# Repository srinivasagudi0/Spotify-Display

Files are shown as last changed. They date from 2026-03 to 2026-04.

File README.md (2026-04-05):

# 🎵 Spotify Display (ESP32 + TFT)

A small project I made that shows my current Spotify track on a TFT screen using an ESP32.

---

## 🚀 Features

- Shows song name + artist  
- Connects to Spotify over WiFi  
- 3 buttons: play/pause, next, previous  
- Runs on ESP32 C3 Mini  

---

## 🧠 What I Did

- Set up Spotify API on the ESP32  
- Built a simple UI for the display  
- Wired buttons for playback control  
- Made a compact enclosure  

---

## 🧰 Parts

- ESP32 C3 Mini  
- 1.8" TFT (ST7735)  
- 3 buttons  
- Wires / soldering  

---

## 🔌 Wiring

| Part | Pin |
|---|-----|
| TFT CS | 5 |
| TFT DC | 2 |
| TFT RST  | 4 |
| TFT MOSI | 6 |
| TFT SCLK | 7 |
| Prev Btn | 8 |
| Play Btn | 9 |
| Next Btn | 10 |

---

## ▶️ How It Works

ESP32 connects to WiFi → gets current track from Spotify → displays it → buttons control playback.

---

## 🛠 Future Ideas

- Album art  
- Battery  
- Better UI  
- Volume control  

---

## 👤 Me

Srinivasa Gudi  
https://github.com/srinivasagudi0

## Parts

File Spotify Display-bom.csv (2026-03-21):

Name | Purpose | Cost Per Item (USD) | Quantity | Total (USD) | Link | Distributor
Soldering Iron | TO make wires permenant | 9.99 | 1 | 9.99 | https://www.amazon.com/Soldering-soldering-solder-adjustable-temperature/dp/B09DY7CCW5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 | Amazon
M4 inset nuts | Screw holders | 6.99 | 1 | 6.99 | https://www.amazon.com/Knurled-Threaded-Embedding-Printing-Automotive/dp/B0DPQH2KX7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 | Amazon
Button | Play/Pause/Forward buttons | 4.00 | 1 | 4.00 | https://www.amazon.com/gp/product/B0DFXVK6G4/ref=sw_img_1?smid=A3OR18NVOUCB97&psc=1 | Amazon
1.8" TFT Display | The screen to display things. | 8.48 | 1 | 8.48 | https://www.amazon.com/Display-Module-128%C3%97160-Serial-ST7735/dp/B07R413JTD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 | Amazon
ESP32 Board | runs code, connects to WiFi, talks to Spotify. | 9.99 | 1 | 9.99 | https://www.amazon.com/gp/product/B0718T232Z/ref=sw_img_1?smid=A30QSGOJR8LMXA&th=1 | Amazon

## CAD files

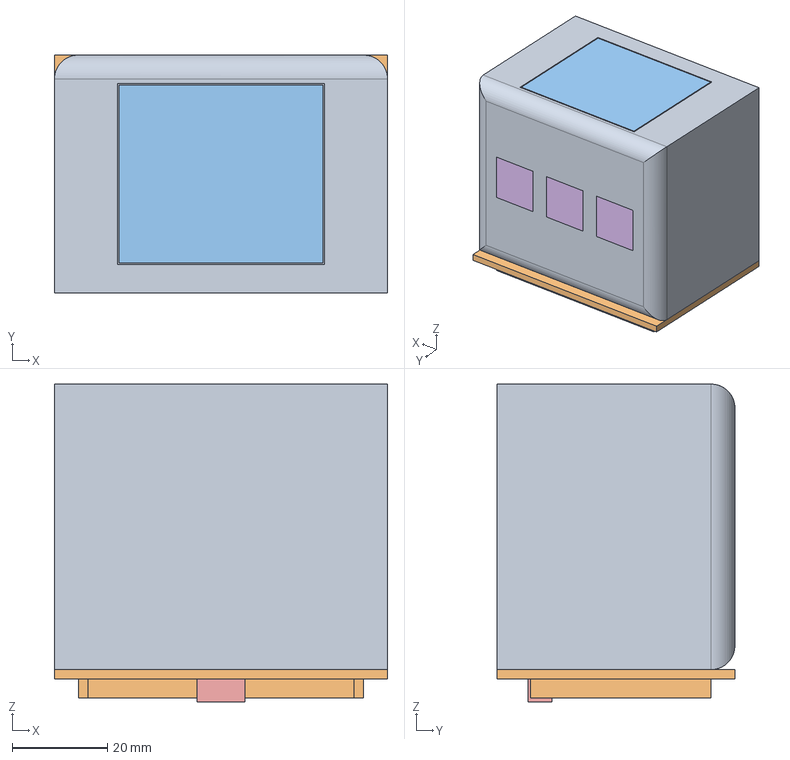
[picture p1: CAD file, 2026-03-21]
spotify_display_assembled.step
70.0 x 50.0 x 66.8 mm
case
back_lid
screen_placeholder
esp32_placeholder
switch_placeholders

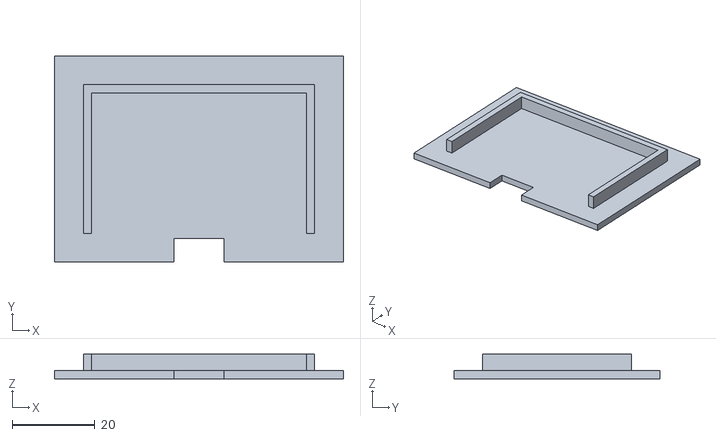
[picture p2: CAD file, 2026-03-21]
cad/spotify_display_back_lid.stl
70.0 x 50.0 x 6.00

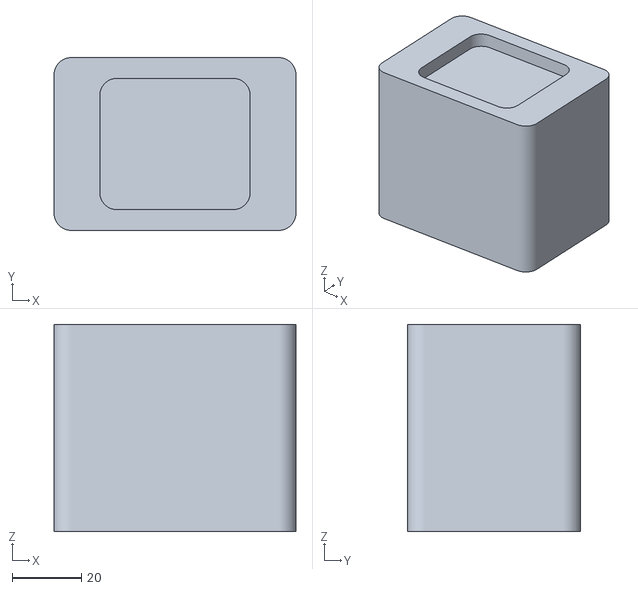
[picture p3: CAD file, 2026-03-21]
cad/spotify_display_case.stl
70.0 x 50.0 x 60.0

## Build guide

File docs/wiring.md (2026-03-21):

# Wiring Guide

## TFT Display to ESP32 C3 Mini

| TFT Pin | ESP32 Pin |
|---|---|
| VCC | 3V3 |
| GND | GND |
| CS | GPIO 5 |
| DC | GPIO 2 |
| RST | GPIO 4 |
| SDA / MOSI | GPIO 6 |
| SCL / SCLK | GPIO 7 |
| LED / BL | 3V3 |

## Buttons

Each button should connect one side to the GPIO pin and the other side to GND.
The sketch uses `INPUT_PULLUP`, so no external pull-up resistor is required.

| Button | ESP32 Pin |
|---|---|
| Previous | GPIO 8 |
| Play / Pause | GPIO 9 |
| Next | GPIO 10 |

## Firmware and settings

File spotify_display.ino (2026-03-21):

#include <Arduino.h>
#include <ArduinoJson.h>
#include <Adafruit_GFX.h>
#include <Adafruit_ST7735.h>
#include <WiFi.h>
#include <SpotifyEsp32.h>
#include <SPI.h>

// =========================
// Pin configuration
// Update these if needed for your exact C3 Mini wiring.
// =========================
#define TFT_CS    5
#define TFT_DC    2
#define TFT_RST   4
#define TFT_MOSI  6
#define TFT_SCLK  7

#define BTN_PREV  8
#define BTN_PLAY  9
#define BTN_NEXT  10

// =========================
// Credentials
// =========================
const char* SSID = "YOUR_WIFI_SSID";
const char* PASSWORD = "YOUR_WIFI_PASSWORD";
const char* CLIENT_ID = "YOUR_CLIENT_ID";
const char* CLIENT_SECRET = "YOUR_CLIENT_SECRET";

// =========================
// Globals
// =========================
Spotify sp(CLIENT_ID, CLIENT_SECRET);
Adafruit_ST7735 tft = Adafruit_ST7735(TFT_CS, TFT_DC, TFT_MOSI, TFT_SCLK, TFT_RST);

String lastArtist = "";
String lastTrack = "";
unsigned long lastPoll = 0;
const unsigned long pollInterval = 2000;

bool lastPrevState = HIGH;
bool lastPlayState = HIGH;
bool lastNextState = HIGH;

void drawCenteredText(const String& text, int y, uint8_t textSize) {
  int16_t x1, y1;
  uint16_t w, h;
  tft.setTextSize(textSize);
  tft.getTextBounds(text.c_str(), 0, y, &x1, &y1, &w, &h);
  int x = (160 - w) / 2;
  if (x < 0) x = 0;
  tft.setCursor(x, y);
  tft.print(text);
}

void drawUI(const String& artist, const String& track, bool isPlaying) {
  tft.fillScreen(ST77XX_BLACK);

  tft.drawRect(4, 4, 152, 120, ST77XX_WHITE);
  tft.setTextColor(ST77XX_WHITE);

  tft.setTextSize(1);
  tft.setCursor(12, 12);
  tft.print("Spotify Display");

  tft.drawLine(10, 24, 150, 24, ST77XX_WHITE);

  tft.setTextColor(ST77XX_GREEN);
  drawCenteredText(track, 40, 2);

  tft.setTextColor(ST77XX_CYAN);
  drawCenteredText(artist, 75, 1);

  tft.setTextColor(isPlaying ? ST77XX_GREEN : ST77XX_RED);
  tft.setCursor(12, 104);
  tft.print(isPlaying ? "Status: Playing" : "Status: Paused");
}

void connectWiFi() {
  Serial.print("Connecting to WiFi");
  WiFi.begin(SSID, PASSWORD);

  while (WiFi.status() != WL_CONNECTED) {
    delay(500);
    Serial.print(".");
  }

  Serial.println();
  Serial.println("WiFi connected");
  Serial.print("IP: ");
  Serial.println(WiFi.localIP());
}

void authenticateSpotify() {
  Serial.println("Starting Spotify authentication...");
  sp.begin();

  while (!sp.is_auth()) {
    sp.handle_client();
    delay(50);
  }

  Serial.println("Spotify authenticated");
}

void handleButtons() {
  bool currentPrev = digitalRead(BTN_PREV);
  bool currentPlay = digitalRead(BTN_PLAY);
  bool currentNext = digitalRead(BTN_NEXT);

  if (lastPrevState == HIGH && currentPrev == LOW) {
    Serial.println("Previous");
    sp.previous();
    delay(250);
  }

  if (lastPlayState == HIGH && currentPlay == LOW) {
    Serial.println("Play / Pause");
    sp.start_resume_playback();
    delay(250);
  }

  if (lastNextState == HIGH && currentNext == LOW) {
    Serial.println("Next");
    sp.skip();
    delay(250);
  }

  lastPrevState = currentPrev;
  lastPlayState = currentPlay;
  lastNextState = currentNext;
}

void setup() {
  Serial.begin(115200);

  pinMode(BTN_PREV, INPUT_PULLUP);
  pinMode(BTN_PLAY, INPUT_PULLUP);
  pinMode(BTN_NEXT, INPUT_PULLUP);

  tft.initR(INITR_BLACKTAB);
  tft.setRotation(1);
  tft.fillScreen(ST77XX_BLACK);
  tft.setTextWrap(false);
  tft.setTextColor(ST77XX_WHITE);
  tft.setCursor(10, 10);
  tft.print("Booting...");

  connectWiFi();
  authenticateSpotify();

  drawUI("Waiting...", "No track", false);
}

void loop() {
  handleButtons();

  if (millis() - lastPoll >= pollInterval) {
    lastPoll = millis();

    String currentArtist = sp.current_artist_names();
    String currentTrack = sp.current_track_name();
    bool playing = sp.is_playing();

    bool validArtist = !currentArtist.isEmpty() && currentArtist != "Something went wrong";
    bool validTrack = !currentTrack.isEmpty() && currentTrack != "Something went wrong" && currentTrack != "null";

    if (validArtist && validTrack) {
      if (currentArtist != lastArtist || currentTrack != lastTrack) {
        lastArtist = currentArtist;
        lastTrack = currentTrack;
        Serial.println("Track updated");
        Serial.println("Artist: " + currentArtist);
        Serial.println("Track: " + currentTrack);
      }
      drawUI(currentArtist, currentTrack, playing);
    } else {
      drawUI("Spotify", "No active track", false);
    }
  }
}
